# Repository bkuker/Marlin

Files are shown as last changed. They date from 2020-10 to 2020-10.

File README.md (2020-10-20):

This is a Marlin config for a 1st Makerspace "Steam Engine" 3d Printer.
The hardware has been customized for the REclaimED Makerspace in
Poultney, VT.

You probably do not want to use this fork of Marlin.

# Changes to 1st Makerspace Steam Engine

## Hardware Changes

1. Replaced hot end nozzle, block, thermistor and tube.
2. Hot end fan cools all the time
3. Added part cooler, custom fan mount and blow tip
4. Replaced extruder cable management to make replacing cables possible
5. Moved end stops to be outside of software print area
6. Z axis top bearings shot, printed new holder for more common size.
7. Removed and cleaned z lead screws. Something had gotten on thermal
8. Replaced arduino
9. Replaced Z driver

## Software Changes

Fresh Marlin install, customized by hand.

## Slicer Settings

### New Startup

Adds a wipe similar to Prusa

```
G28 ; home all axes
G1 Z5 F5000 ; lift nozzle

G1 Z0 Y5 X15 F1000.0 ; go outside print area
G92 E0.0
G1 X90.0 E14  F1000.0 ; intro line
G1 X150.0 E18  F1000.0 ; intro line
G92 E0.0
```

# Notes

## Z Axis

2mm pitch
assume 200 Steps
100 per mm

## wires
Endstop order Left to Right
Red Pink Black Green Brown Yellow

E Stepper wires
Blue (marked) Yellow Green Red

# Old Firmware

None of the features to allow us to get the old settings back were enabled.
What Jerks! So I replaced the Arduino so I can keep the old one

## Startup
```
Connecting...
start
Printer is now online.
echo: External Reset
Marlin 2.0.0
echo: Last Updated: Jan 25 2015 15:09:44 | Author: (NagyA)
echo: Free Memory: 5527  PlannerBufferBytes: 1232
Using tool 0.
echo:Active Extruder: 0
```

## M115
```
>>> m115
SENDING:M115
FIRMWARE_NAME:Marlin V1; Sprinter/grbl mashup for gen6 FIRMWARE_URL:http://www.mendel-parts.com PROTOCOL_VERSION:1.0 MACHINE_TYPE:Mendel EXTRUDER_COUNT:1
```

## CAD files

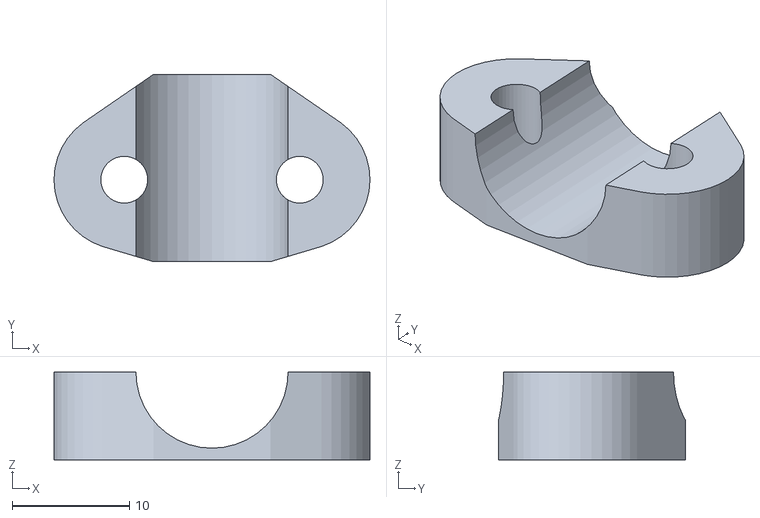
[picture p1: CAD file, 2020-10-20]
Parts/clamp.stl
27.0 x 16.0 x 7.50

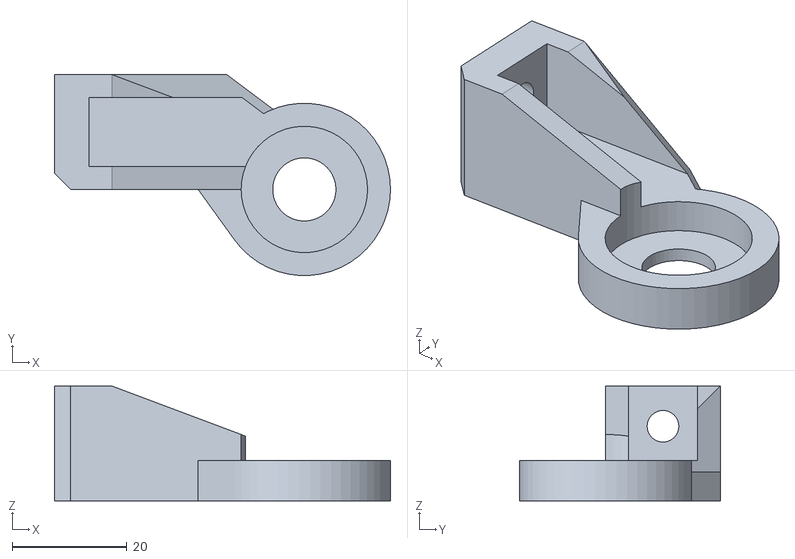
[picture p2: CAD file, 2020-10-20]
Parts/z.stl
58.5 x 35.0 x 20.0

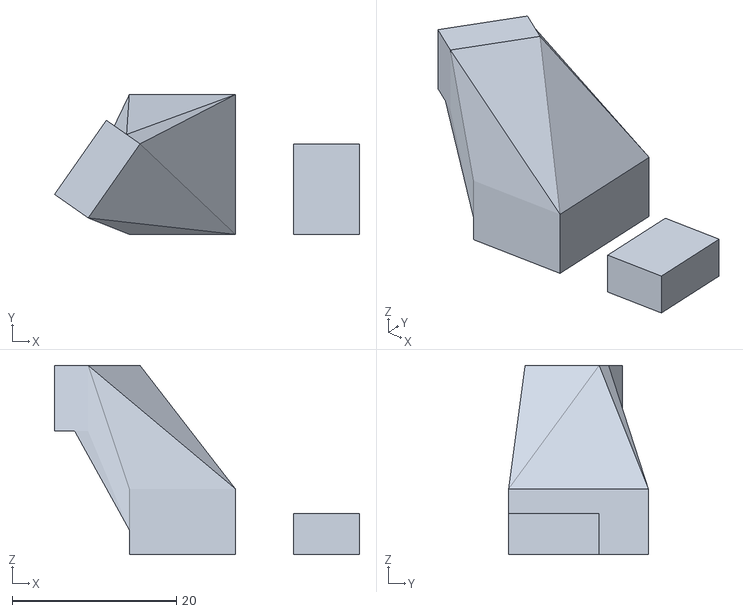
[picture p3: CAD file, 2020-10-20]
Parts/tip.stl
37.1 x 17.0 x 23.0

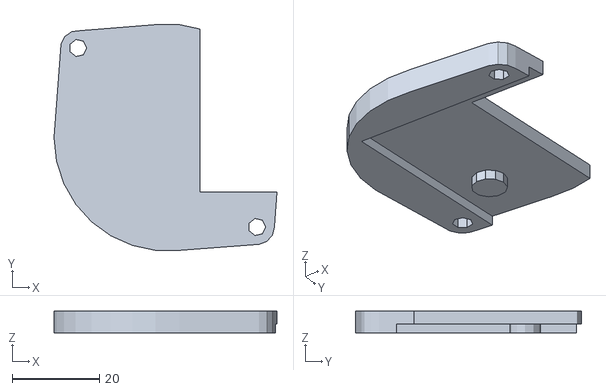
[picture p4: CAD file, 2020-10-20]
Parts/fan.stl
51.1 x 51.7 x 5.00

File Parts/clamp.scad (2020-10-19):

//This is the cable clamp used on the extruder cables
$fn = 40;

translate([0,0,16])
    rotate([0,180,0])
        difference(){
            hull(){
                translate([15/2,0,0]){
                    cylinder(16,6,6);
                }
                translate([-15/2,0,0]){
                    cylinder(16,6,6);
                }
                translate([-5,-7,0])
                    cube([10,16,16],false);
            }

            union(){
                translate([15/2,0,0]){
                    cylinder(18,2,2);
                }
                translate([-15/2,0,0]){
                    cylinder(18,2,2);
                }
            }


            translate([0,20,17/2])
                rotate([90,0,0])
                    #cylinder(50,6.5,6.5);

            translate([-50,-50,0])
                cube([100,100,17/2], false);
        }

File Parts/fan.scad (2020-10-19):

//This is the plate that holds the part cooling fan

HoleR = 7/2;
HoleX = 5;
HoleY = 26;
BaseT = 2;

module base(){
color("#ff8899"){
    difference(){
        cube([100,49,BaseT]);
        translate([HoleX+HoleR,HoleY+HoleR,-1])
            cylinder(BaseT*2,HoleR,HoleR,false);
    }
    translate([0,49,0])
    cube([100,BaseT,60]);
}
}


FanHD = 58;
FanT = 15;
FanD = 48;
fs = FanHD / sqrt(2);
module fan(){
    color("#666666"){
        translate([-4,-4,-(FanT)]){
            translate([fs/2,fs/2,FanT/2])
                cylinder(FanT, FanD/2, FanD/2, true);
            hull(){
            translate([0,fs,0])
                cylinder(FanT, 3, 3);
            translate([fs,0,0])
                cylinder(FanT, 3, 3);
            }
            translate([0,fs,0])
                cylinder(30, 2, 2);
            translate([fs,0,0])
                cylinder(30, 2, 2);
        }
    }
}

module extruder(){
    color("#444444")
    translate([24,4,BaseT])
        cube([20,43,43]);
}

//base();
//fan();
//extruder();
T = 5;

difference(){
    translate([-4,-4,T/2]){
        hull(){
            translate([fs/2,fs/2,0])
                cylinder(T, 2+FanD/2, 2+FanD/2, true);
            translate([0,fs,0])
                cylinder(T, 4, 4, true);
            translate([fs,0,0])
                cylinder(T, 4, 4, true);
        }
    }
    union(){
        base();
        fan();
        extruder();
    }
}

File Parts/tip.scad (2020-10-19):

//This is the top for the part cooling fan.
//Printed in two parts No infill, no bottom layer.
//Two top layers for the big part, no top layer for the small part.
//Hole must be cut in the larger part after printing, too lazy to do
//the scad work.

cube([12.9,17,5]);

hull(){
translate([0,0,3])
    cube([12.9,17,5]);
translate([-5,2,15])
    rotate([-35,-90,0])
    cube([8,11,2]);
}

translate([-5,2,15])
    rotate([-35,-90,0])
    cube([8,11,5]);

translate([20,0,0])
    cube([8,11,5]);

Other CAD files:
Parts/z.scad

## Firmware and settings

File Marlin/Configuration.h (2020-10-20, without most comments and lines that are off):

#pragma once
#define CONFIGURATION_H_VERSION 020007
#define STRING_CONFIG_H_AUTHOR "(Bill Kuker, REclaimED Poultney)" // Who made the changes.
#define SHOW_BOOTSCREEN
#define SERIAL_PORT 0
#define BAUDRATE 250000
  #define MOTHERBOARD BOARD_RAMPS_14_EFB
#define CUSTOM_MACHINE_NAME "REclaimED Steam Engine"
#define EXTRUDERS 1
#define DEFAULT_NOMINAL_FILAMENT_DIA 1.75
#define TEMP_SENSOR_0 11
#define TEMP_SENSOR_1 0
#define TEMP_SENSOR_2 0
#define TEMP_SENSOR_3 0
#define TEMP_SENSOR_4 0
#define TEMP_SENSOR_5 0
#define TEMP_SENSOR_6 0
#define TEMP_SENSOR_7 0
#define TEMP_SENSOR_BED 1
#define TEMP_SENSOR_PROBE 0
#define TEMP_SENSOR_CHAMBER 0
#define DUMMY_THERMISTOR_998_VALUE 25
#define DUMMY_THERMISTOR_999_VALUE 100
#define MAX_REDUNDANT_TEMP_SENSOR_DIFF 10
#define TEMP_RESIDENCY_TIME     10  // (seconds) Time to wait for hotend to "settle" in M109
#define TEMP_WINDOW              1  // (°C) Temperature proximity for the "temperature reached" timer
#define TEMP_HYSTERESIS          3  // (°C) Temperature proximity considered "close enough" to the target
#define TEMP_BED_RESIDENCY_TIME 10  // (seconds) Time to wait for bed to "settle" in M190
#define TEMP_BED_WINDOW          1  // (°C) Temperature proximity for the "temperature reached" timer
#define TEMP_BED_HYSTERESIS      3  // (°C) Temperature proximity considered "close enough" to the target
#define HEATER_0_MINTEMP   5
#define HEATER_1_MINTEMP   5
#define HEATER_2_MINTEMP   5
#define HEATER_3_MINTEMP   5
#define HEATER_4_MINTEMP   5
#define HEATER_5_MINTEMP   5
#define HEATER_6_MINTEMP   5
#define HEATER_7_MINTEMP   5
#define BED_MINTEMP        5
#define HEATER_0_MAXTEMP 275
#define HEATER_1_MAXTEMP 275
#define HEATER_2_MAXTEMP 275
#define HEATER_3_MAXTEMP 275
#define HEATER_4_MAXTEMP 275
#define HEATER_5_MAXTEMP 275
#define HEATER_6_MAXTEMP 275
#define HEATER_7_MAXTEMP 275
#define BED_MAXTEMP      150
#define PIDTEMP
#define BANG_MAX 255     // Limits current to nozzle while in bang-bang mode; 255=full current
#define PID_MAX BANG_MAX // Limits current to nozzle while PID is active (see PID_FUNCTIONAL_RANGE below); 255=full current
#define PID_K1 0.95      // Smoothing factor within any PID loop
    #define DEFAULT_Kp 31.77
    #define DEFAULT_Ki 6.26
    #define DEFAULT_Kd 40.34
#define MAX_BED_POWER 255 // limits duty cycle to bed; 255=full current
  #define PID_FUNCTIONAL_RANGE 10 // If the temperature difference between the target temperature and the actual temperature
#define PREVENT_COLD_EXTRUSION
#define EXTRUDE_MINTEMP 170
#define PREVENT_LENGTHY_EXTRUDE
#define EXTRUDE_MAXLENGTH 200
#define THERMAL_PROTECTION_HOTENDS // Enable thermal protection for all extruders
#define THERMAL_PROTECTION_BED     // Enable thermal protection for the heated bed
#define THERMAL_PROTECTION_CHAMBER // Enable thermal protection for the heated chamber
#define USE_XMIN_PLUG
#define USE_YMIN_PLUG
#define USE_ZMIN_PLUG
#define USE_XMAX_PLUG
#define USE_YMAX_PLUG
#define USE_ZMAX_PLUG
#define ENDSTOPPULLUPS
#define X_MIN_ENDSTOP_INVERTING true // Set to true to invert the logic of the endstop.
#define Y_MIN_ENDSTOP_INVERTING true // Set to true to invert the logic of the endstop.
#define Z_MIN_ENDSTOP_INVERTING true // Set to true to invert the logic of the endstop.
#define X_MAX_ENDSTOP_INVERTING true // Set to true to invert the logic of the endstop.
#define Y_MAX_ENDSTOP_INVERTING true // Set to true to invert the logic of the endstop.
#define Z_MAX_ENDSTOP_INVERTING true // Set to true to invert the logic of the endstop.
#define Z_MIN_PROBE_ENDSTOP_INVERTING true // Set to true to invert the logic of the probe.
#define DEFAULT_AXIS_STEPS_PER_UNIT   { 88, 88, 1511.81, 95 }
#define DEFAULT_MAX_FEEDRATE          { 300, 300, 5, 25 }
#define DEFAULT_MAX_ACCELERATION      { 3000, 3000, 100, 10000 }
#define DEFAULT_ACCELERATION          3000    // X, Y, Z and E acceleration for printing moves
#define DEFAULT_RETRACT_ACCELERATION  3000    // E acceleration for retracts
#define DEFAULT_TRAVEL_ACCELERATION   3000    // X, Y, Z acceleration for travel (non printing) moves
#define DEFAULT_EJERK    5.0  // May be used by Linear Advance
  #define JUNCTION_DEVIATION_MM 0.013 // (mm) Distance from real junction edge
  #define JD_HANDLE_SMALL_SEGMENTS    // Use curvature estimation instead of just the junction angle
#define Z_MIN_PROBE_USES_Z_MIN_ENDSTOP_PIN
#define NOZZLE_TO_PROBE_OFFSET { 10, 10, 0 }
#define PROBING_MARGIN 10
#define XY_PROBE_SPEED (133*60)
#define Z_PROBE_SPEED_FAST HOMING_FEEDRATE_Z
#define Z_PROBE_SPEED_SLOW (Z_PROBE_SPEED_FAST / 2)
#define Z_CLEARANCE_DEPLOY_PROBE   10 // Z Clearance for Deploy/Stow
#define Z_CLEARANCE_BETWEEN_PROBES  5 // Z Clearance between probe points
#define Z_CLEARANCE_MULTI_PROBE     5 // Z Clearance between multiple probes
#define Z_PROBE_LOW_POINT          -2 // Farthest distance below the trigger-point to go before stopping
#define Z_PROBE_OFFSET_RANGE_MIN -20
#define Z_PROBE_OFFSET_RANGE_MAX 20
#define X_ENABLE_ON 0
#define Y_ENABLE_ON 0
#define Z_ENABLE_ON 0
#define E_ENABLE_ON 0 // For all extruders
#define DISABLE_X false
#define DISABLE_Y false
#define DISABLE_Z false
#define DISABLE_E false             // Disable the extruder when not stepping
#define DISABLE_INACTIVE_EXTRUDER   // Keep only the active extruder enabled
#define INVERT_X_DIR false
#define INVERT_Y_DIR false
#define INVERT_Z_DIR false
#define INVERT_E0_DIR false
#define INVERT_E1_DIR false
#define INVERT_E2_DIR false
#define INVERT_E3_DIR false
#define INVERT_E4_DIR false
#define INVERT_E5_DIR false
#define INVERT_E6_DIR false
#define INVERT_E7_DIR false
#define Z_AFTER_HOMING  10      // (mm) Height to move to after homing Z
#define X_HOME_DIR -1
#define Y_HOME_DIR -1
#define Z_HOME_DIR -1
#define X_BED_SIZE 200
#define Y_BED_SIZE 200
#define X_MIN_POS -4.4
#define Y_MIN_POS -4
#define Z_MIN_POS 0
#define X_MAX_POS X_BED_SIZE
#define Y_MAX_POS Y_BED_SIZE
#define Z_MAX_POS 130
#define MIN_SOFTWARE_ENDSTOPS
  #define MIN_SOFTWARE_ENDSTOP_X
  #define MIN_SOFTWARE_ENDSTOP_Y
  #define MIN_SOFTWARE_ENDSTOP_Z
#define MAX_SOFTWARE_ENDSTOPS
  #define MAX_SOFTWARE_ENDSTOP_X
  #define MAX_SOFTWARE_ENDSTOP_Y
  #define MAX_SOFTWARE_ENDSTOP_Z
#define HOMING_FEEDRATE_XY (50*60)
#define HOMING_FEEDRATE_Z  (4*60)
#define VALIDATE_HOMING_ENDSTOPS
#define EEPROM_CHITCHAT       // Give feedback on EEPROM commands. Disable to save PROGMEM.
#define EEPROM_BOOT_SILENT    // Keep M503 quiet and only give errors during first load
#define HOST_KEEPALIVE_FEATURE        // Disable this if your host doesn't like keepalive messages
#define DEFAULT_KEEPALIVE_INTERVAL 2  // Number of seconds between "busy" messages. Set with M113.
#define BUSY_WHILE_HEATING            // Some hosts require "busy" messages even during heating
#define PREHEAT_1_LABEL       "PLA"
#define PREHEAT_1_TEMP_HOTEND 180
#define PREHEAT_1_TEMP_BED     70
#define PREHEAT_1_FAN_SPEED     0 // Value from 0 to 255
#define PREHEAT_2_LABEL       "ABS"
#define PREHEAT_2_TEMP_HOTEND 240
#define PREHEAT_2_TEMP_BED    110
#define PREHEAT_2_FAN_SPEED     0 // Value from 0 to 255
#define PRINTJOB_TIMER_AUTOSTART
#define LCD_LANGUAGE en
#define DISPLAY_CHARSET_HD44780 JAPANESE
#define LCD_INFO_SCREEN_STYLE 0
#define SOFT_PWM_SCALE 0
#define SERVO_DELAY { 300 }

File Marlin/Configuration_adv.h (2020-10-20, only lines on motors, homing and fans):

#define E0_AUTO_FAN_PIN 4
#define E1_AUTO_FAN_PIN -1
#define E2_AUTO_FAN_PIN -1
#define E3_AUTO_FAN_PIN -1
#define E4_AUTO_FAN_PIN -1
#define E5_AUTO_FAN_PIN -1
#define E6_AUTO_FAN_PIN -1
#define E7_AUTO_FAN_PIN -1
#define CHAMBER_AUTO_FAN_PIN -1
#define HOMING_BUMP_MM      { 5, 5, 2 }       // (mm) Backoff from endstops after first bump
#define HOMING_BUMP_DIVISOR { 2, 2, 4 }       // Re-Bump Speed Divisor (Divides the Homing Feedrate)
#define QUICK_HOME                          // If G28 contains XY do a diagonal move first
#define MICROSTEP_MODES { 16, 16, 16, 16, 16, 16 } // [1,2,4,8,16]

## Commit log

2020-10-19 Initial Work
    [Configuration.h, Configuration_adv.h, clamp.scad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]
2020-10-20 More updates
    [Configuration.h, Configuration_adv.h]
2020-10-20 Parts, docs, updates
    [Configuration.h, clamp.stl, fan.stl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]

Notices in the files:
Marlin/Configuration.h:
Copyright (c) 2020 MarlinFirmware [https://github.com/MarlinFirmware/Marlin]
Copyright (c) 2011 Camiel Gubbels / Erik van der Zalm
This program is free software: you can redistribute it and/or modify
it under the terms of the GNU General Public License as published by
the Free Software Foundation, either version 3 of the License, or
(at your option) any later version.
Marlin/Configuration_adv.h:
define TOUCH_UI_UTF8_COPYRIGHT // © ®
